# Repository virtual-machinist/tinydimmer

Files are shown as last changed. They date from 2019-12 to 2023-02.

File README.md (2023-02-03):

# Tinydimmer

LED dimmer with 1-10V control using ATtiny85 microcontroller.

## Motivation

An existing 1-10V controlled LED dimmer in my bathroom doesn't work well with dimmable Osram Superstar 2700K 7.8W MR16 lamps. Its dimming range start is below the minimum power at which the LED lamps start reliably.  
As a result the lamps start with a sudden flash after 1/3 turn of the dimmer controller pot. The 1-10V controlled dimmer I have doesn't have any means to adjust the dimming range, so I had to build my own.

## Parts Used

Here are some notes about parts used for this project. As usual I tend to reuse parts left from previous projects and even something scavenged from broken electronics, so not all parts are listed here.  
The case was printed using black Prusament PETG leftovers from the MK3S printer upgrade (<100g consumed in total).  
The PCB was ordered from JLCPCB. They once again did a fantastic job with Gerbers to delivered PCB in under a week.

`RV1` - originally planned to use a plain MOV (7N431K), but after assembling decided to switch for a Bourns 14D271K GMOV (basically a MOV and a gas discharge tube in one package) for improved safety.

`TR1` - a Hahn EL 305 2051 9V 3W PCB transformer. Just had one laying around. Open circuit gives ~17V AC, drops to 9V AC under rated load.

`D1`..`D4` - 1N5819 Schottky diodes. According to spec can withstand up to 28V RMS reverse voltage with <0.6V drop. Used purely for low voltage drop to give `U1` LDO some margin.

`U1` - Rohm BAJ0CC0T 10V LDO regulator. Probably some other LDO regulator can do, but bear in mind that it must work with `9 x 1.41 - 2 x 0.6 - 10 = 1.49V` dropout if using a 9V AC transformer. Consider choosing another transformer and LM7810 to keep things simpler.

`U2` - Digispark USB clone with ATtiny85 onboard. Brains of the operation.

`J1`, `J2` - CamdenBoss CTB7000 series cut-to-length terminal blocks. Bought actually as CTB7000/36 and, well, cut to length.

`C1` - 820uF 25V low ESR Panasonic capacitor. Could have gotten away with a much smaller value (`U1` spec mandates at least 0.33uF), but just didn't want to put some off-brand ones with smaller value.

`C3` - 47uF 16V tantalum capacitor. According to `U1` spec should be fairly large (at least 22uF) to prevent output oscillation.

`C4`, `C5` - 0.1uF 25V ceramic capacitors. Probably not needed on an actual PCB, but somewhat improved stability while prototyping.

`Q1` - IRL540N, but can be any logic-level n-channel MOSFET having the same pinout.

`R1` - 560R 1/4W resistor to limit current for the 1-10V Busch-Jaeger electronic potentiometer. Spec says it can sink up to 50mA. When prototyping with 12V Vcc I used 1K.

`RV2` - a 25k pot looking like from [ACP](https://www.acptechnologies.com/). I advise to adjust it a notch _below_ dead center so that voltage on its wiper is 4.98-4.99V to be on the safe side. We can remap anything in software after all.

`HS1` and `HS2` were taken from an old ATX PSU. The one for `Q1` isn't actually needed as it barely gets warm with 490Hz PWM. The one for `U1` is recommended though.

## Operation Mode

When referring to microcontroller pins I use the pin layout from the Digispark USB clone I have (`P0`..`P5`).

After power on and boot:

1. `P0` is checked for `HIGH`.

2. If `HIGH`, the control voltage is read as an analog value is from `P2` and divided by 4.

3. If control voltage value is less than low threshold, the minimum PWM value is written to `P1` (in my case 16, i.e. 6% duty cycle).

4. If control voltage value is less than high threshold (in my case 240), the maximum PWM value (255) is written to `P1`. Done because control voltage is not actually 10V, but in 9.7..9.8V range.

5. If `P0` is `LOW`, 0 is written to `P1` turning LEDs completely off.

6. Sleep for 100ms.

## ~~Known Issues~~ Room for Improvement

* Currently the dimmer is powered on constantly since I haven't yet figured out how to program ATTiny85 without a bootloader (or with a minimal one). Default boot times are over 2 seconds. This consumes ~2W at all times, so can add up to ~20kWH a year. Will definitely be revisiting this. [#1](https://github.com/virtual-machinist/tinydimmer/issues/1)

* The case warped a bit after cooling and could use a couple of more screws in the middle of the lid. And/or latches. My FreeCAD-fu is weak ATM. [#2](https://github.com/virtual-machinist/tinydimmer/issues/2)

## Photos

Working prototype:
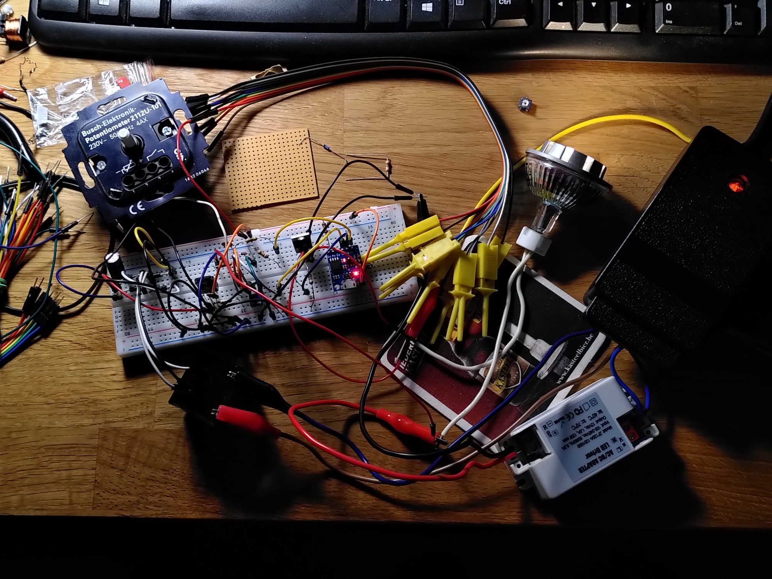
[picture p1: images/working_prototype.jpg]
Working prototype


Starting PCB assembly:
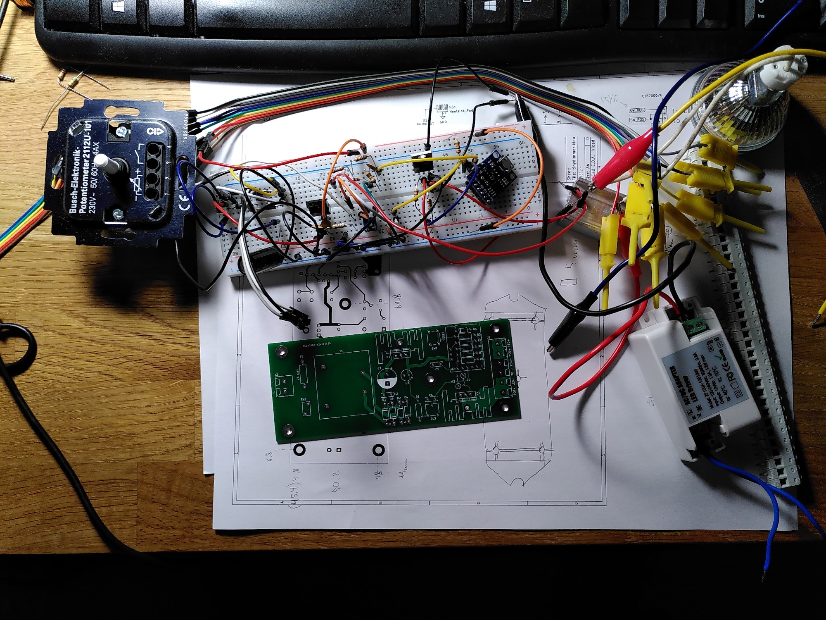
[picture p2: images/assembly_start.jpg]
Starting PCB assembly


Assembled PCB front:
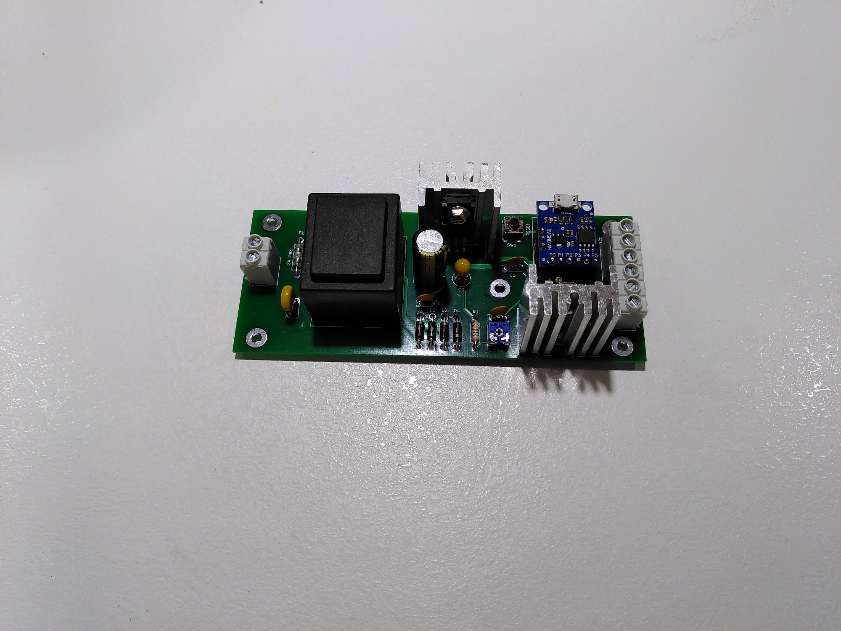
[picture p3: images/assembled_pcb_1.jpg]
Assembled PCB front


Assembled PCB back:
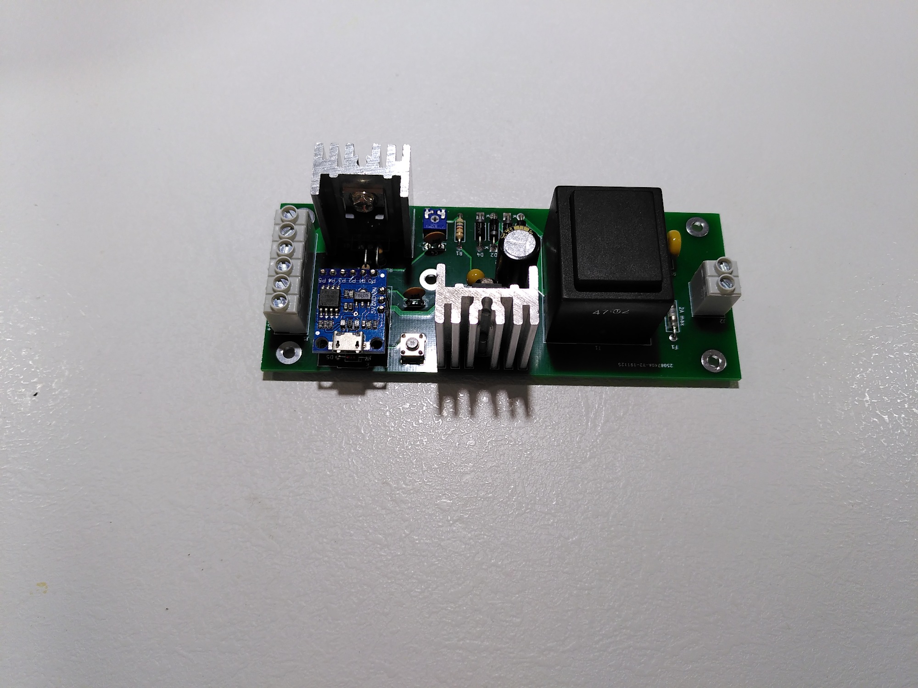
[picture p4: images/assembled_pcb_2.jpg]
Assembled PCB back


Assembled case:
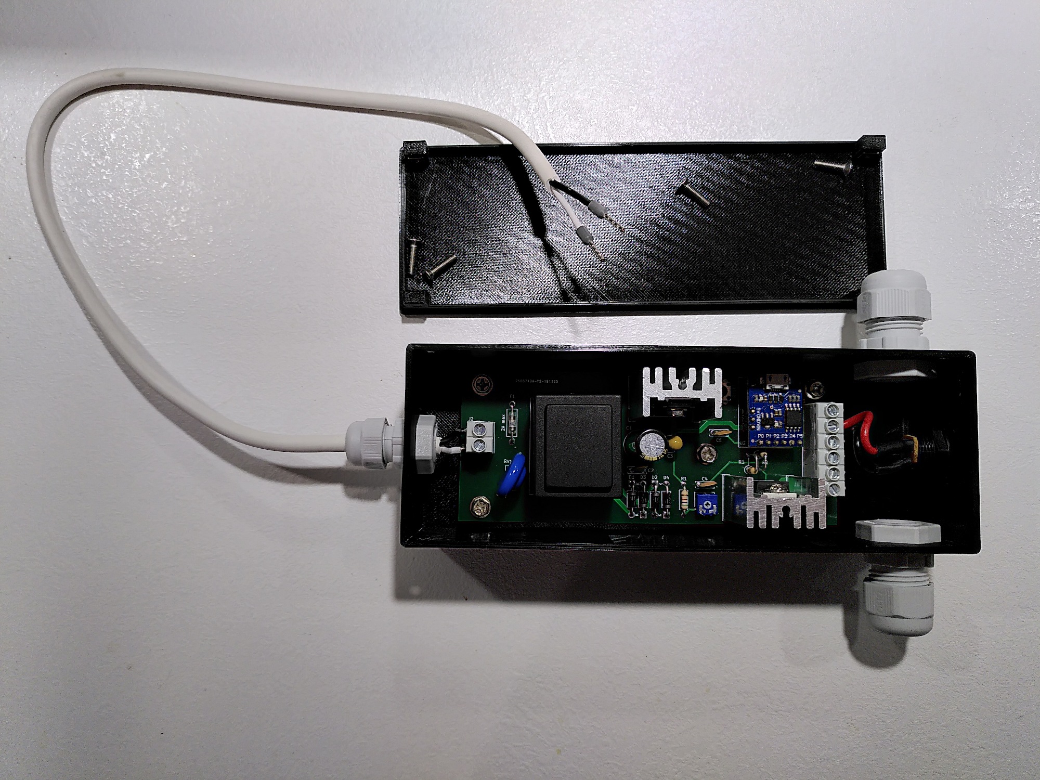
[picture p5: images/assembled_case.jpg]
Assembled case


## Contributing

If you have any questions or remarks for this design, feel free to open an issue.

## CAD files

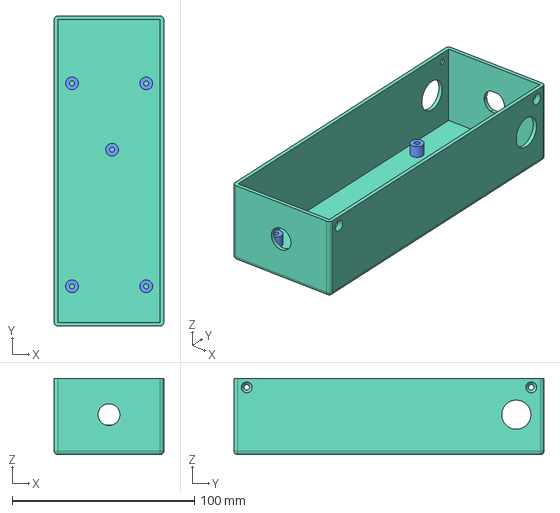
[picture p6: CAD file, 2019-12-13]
housing/Case Lower Half.FCStd
60.2 x 170.2 x 42.0 mm
Mount Shafts

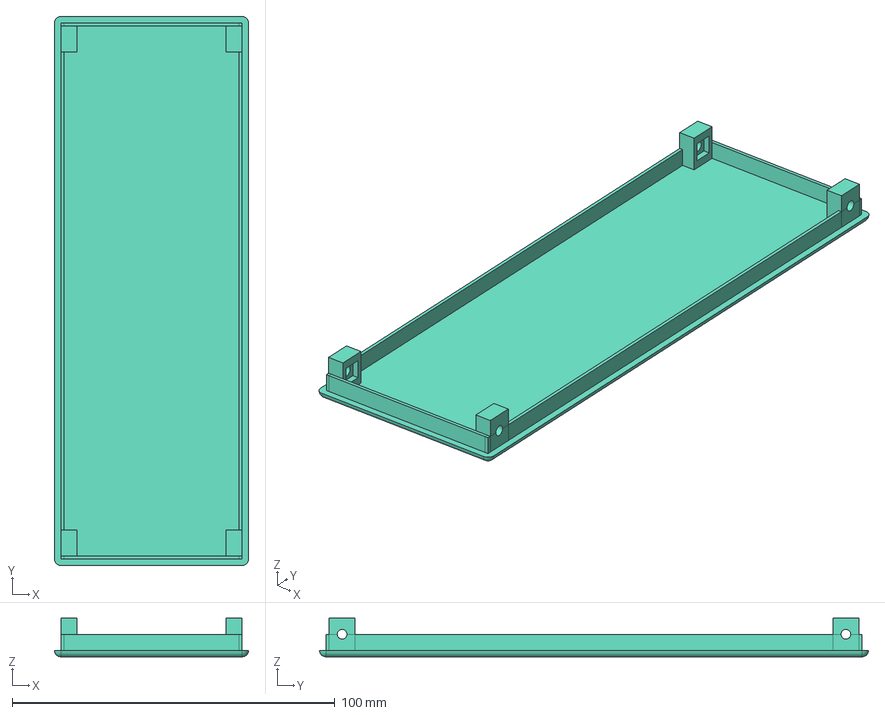
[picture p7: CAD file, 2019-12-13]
housing/Case Upper Half.FCStd
60.2 x 170.2 x 12.0 mm
Cap
Sealed Wall + Mounts

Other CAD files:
housing/Case Lower Half.stl
housing/Case Upper Half.stl

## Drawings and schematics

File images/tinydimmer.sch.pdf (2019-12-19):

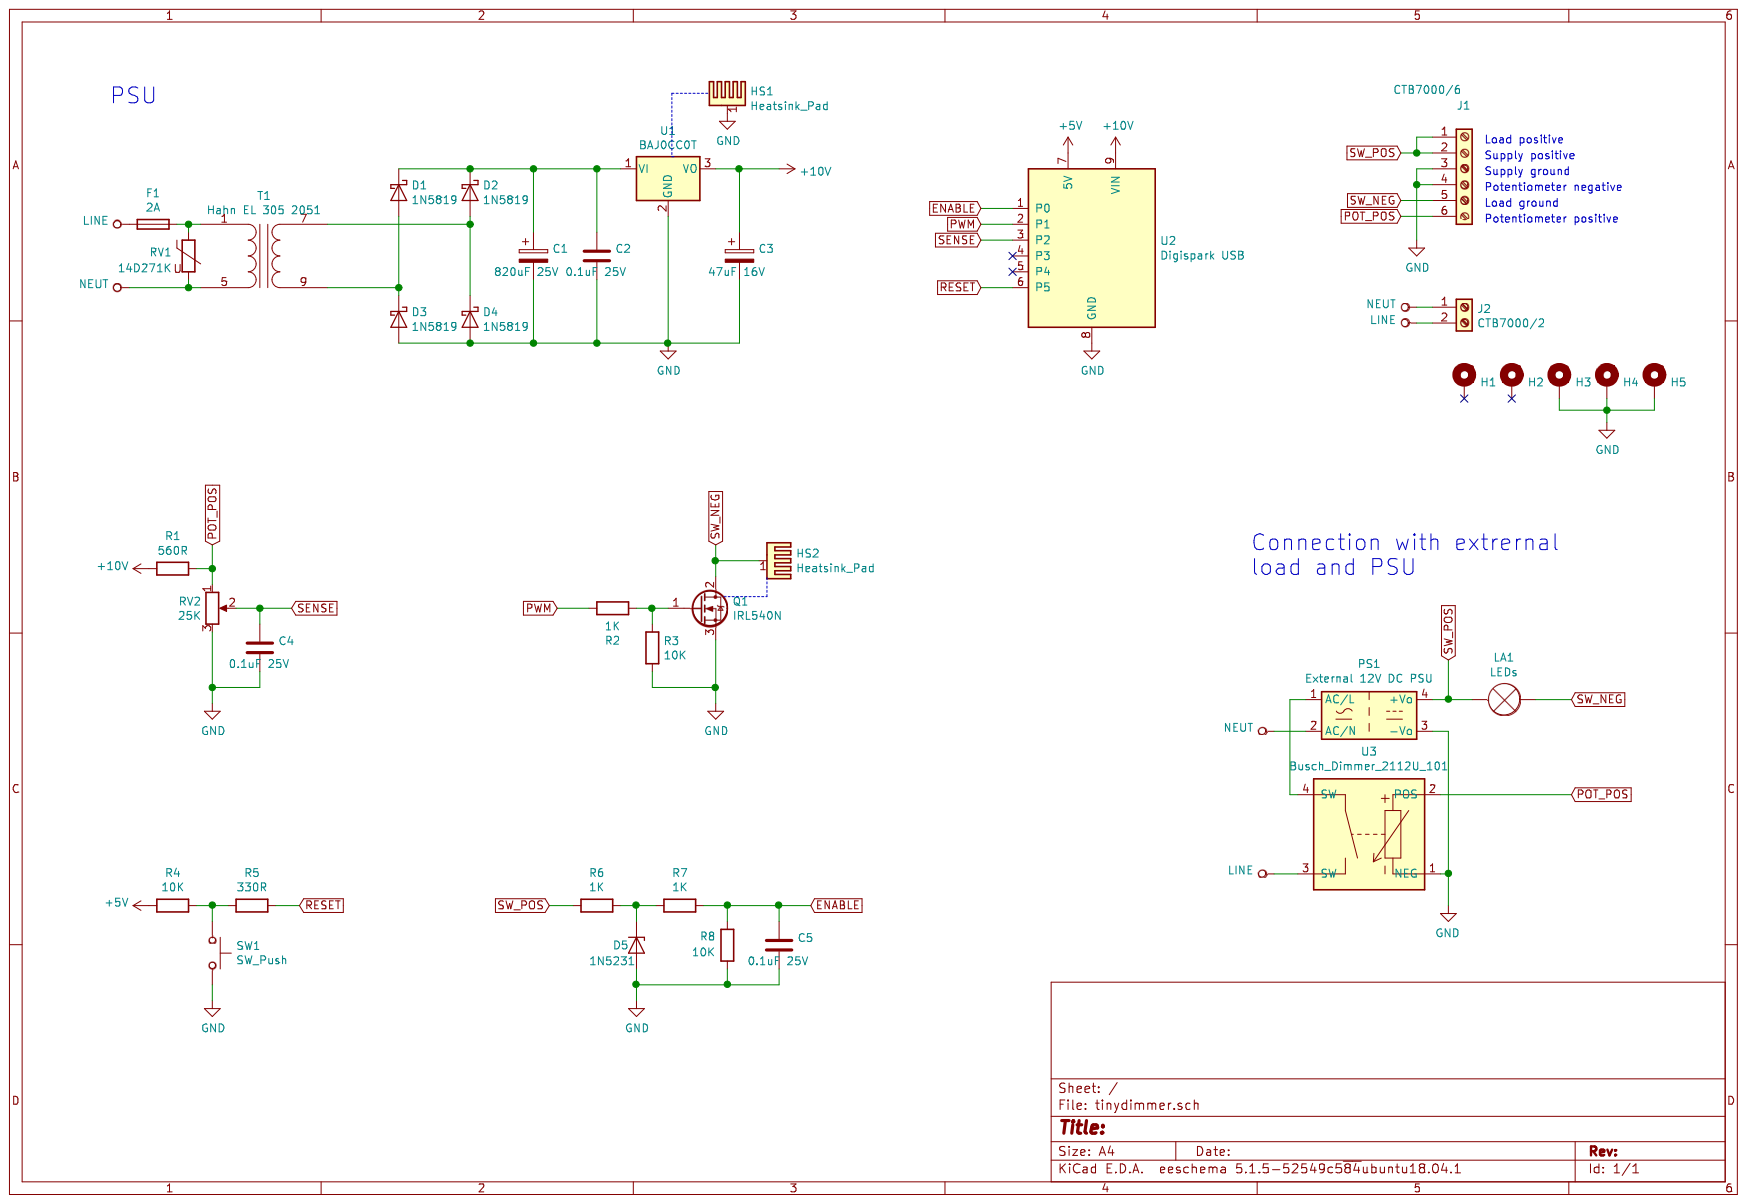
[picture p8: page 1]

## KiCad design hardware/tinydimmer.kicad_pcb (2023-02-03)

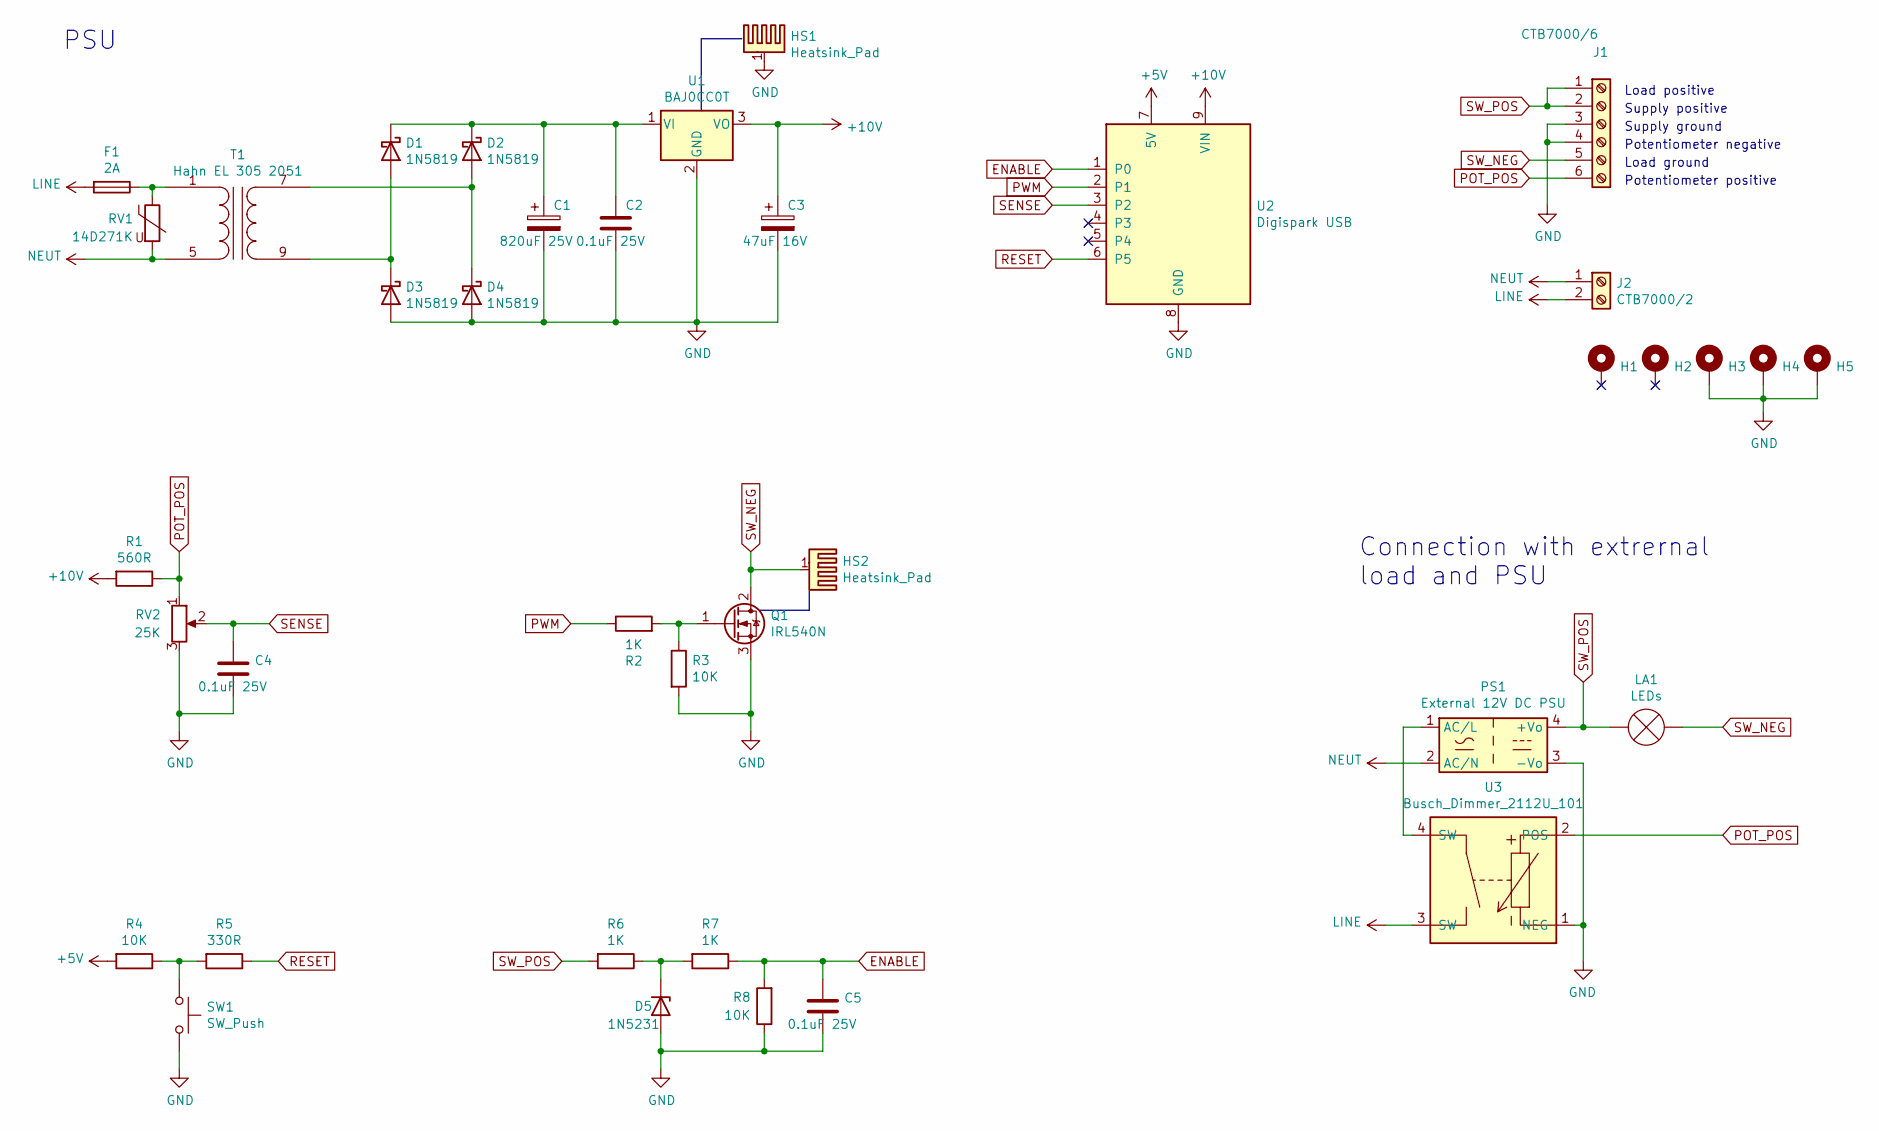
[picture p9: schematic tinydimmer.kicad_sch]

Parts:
C1: 820uF 25V; CP_Radial_D10.0mm_P5.00mm
C2, C4, C5: 0.1uF 25V; C_Disc_D6.0mm_W2.0mm_P3.81mm
C3: 47uF 16V; CP_Radial_Tantal_D5.5mm_P2.50mm
D1, D2, D3, D4: 1N5819; D_DO-41_SOD81_P10.16mm_Horizontal
D5: 1N5231; D_DO-35_SOD27_P7.62mm_Horizontal
F1: 2A; R_Axial_DIN0309_L9.0mm_D3.2mm_P12.70mm_Horizontal_Large_Pads
H1, H2, H3, H4, H5: MountingHole_Pad; MountingHole_3.2mm_M3_Pad
HS1, HS2: Heatsink_Pad; Heatsink_TO220_W23.5mm_L15.0mm_H30.0mm
J1: CTB7000/6; CamdenBoss_CTB7000_6_L30.0mm_P5.0mm
J2: CTB7000/2; CamdenBoss_CTB7000_2_L10.0mm_P5.0mm
LA1: LEDs
PS1: External 12V DC PSU
Q1: IRL540N; TO-220-3_Vertical
R1: 560R; R_Axial_DIN0207_L6.3mm_D2.5mm_P10.16mm_Horizontal
R2: 1K; R_Axial_DIN0207_L6.3mm_D2.5mm_P5.08mm_Vertical
R3: 10K; R_Axial_DIN0207_L6.3mm_D2.5mm_P5.08mm_Vertical
R4, R8: 10K; R_Axial_DIN0207_L6.3mm_D2.5mm_P10.16mm_Horizontal
R5: 330R; R_Axial_DIN0207_L6.3mm_D2.5mm_P10.16mm_Horizontal
R6, R7: 1K; R_Axial_DIN0207_L6.3mm_D2.5mm_P10.16mm_Horizontal
RV1: 14D271K; RV_Disc_D15.5mm_W3.9mm_P7.5mm
RV2: 25K; Potentiometer_ACP_CA6-V2,5_Vertical
SW1: SW_Push; SW_PUSH_6mm_H4.3mm
T1: Hahn EL 305 2051; Hahn_EL_305_2051
U1: BAJ0CC0T; TO-220-3_Vertical
U2: Digispark USB; Digispark_USB
U3: Busch_Dimmer_2112U_101

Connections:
+5V: R4.2, U2.7 (5V)
+10V: C3.1, R1.2, U1.3 (VO), U2.9 (VIN)
ENABLE: C5.1, R7.1, R8.2, U2.1 (P0)
GND: C1.2, C2.2, C3.2, C4.2, C5.2, D3.2 (A), D4.2 (A), D5.2 (A), H3.1, H4.1, H5.1, HS1.1, J1.3, J1.4, PS1.3 (-Vo), Q1.3 (S), R3.2, R8.1, RV2.3, SW1.2, U1.2 (GND), U2.8 (GND), U3.1 (NEG)
LINE: F1.2, J2.2, U3.3 (SW)
NEUT: J2.1, PS1.2 (AC/N), RV1.2, T1.5 (AB)
unnamed: C1.1, C2.1, D1.1 (K), D2.1 (K), U1.1 (VI)
unnamed: D1.2 (A), D3.1 (K), T1.9 (SA)
unnamed: D2.2 (A), D4.1 (K), T1.7 (SB)
unnamed: D5.1 (K), R6.1, R7.2
unnamed: F1.1, RV1.1, T1.1 (AA)
unnamed: PS1.1 (AC/L), U3.4 (SW)
unnamed: Q1.1 (G), R2.2, R3.1
unnamed: R4.1, R5.2, SW1.1
POT_POS: J1.6, R1.1, RV2.1, U3.2 (POS)
PWM: R2.1, U2.2 (P1)
RESET: R5.1, U2.6 (P5)
SENSE: C4.1, RV2.2, U2.3 (P2)
SW_NEG: HS2.1, J1.5, LA1.2 (+), Q1.2 (D)
SW_POS: J1.1, J1.2, LA1.1 (-), PS1.4 (+Vo), R6.2

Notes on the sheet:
Potentiometer negative
PSU
Supply ground
Supply positive
Potentiometer positive
Load positive
Load ground
Connection with extrernal load and PSU

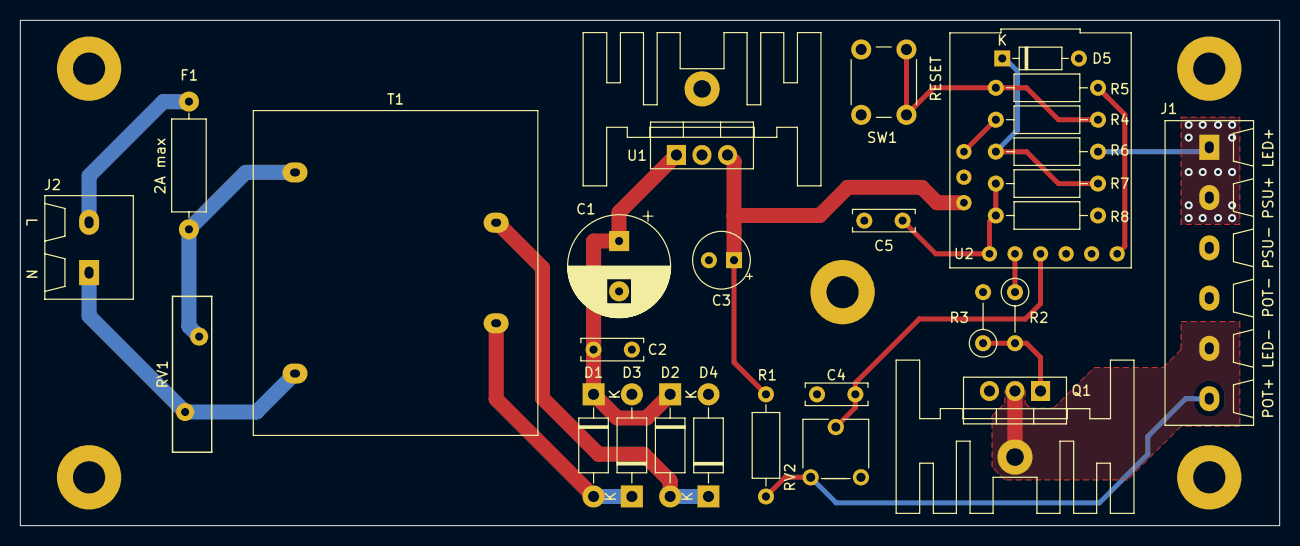
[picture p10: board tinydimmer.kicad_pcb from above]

Board: 2 copper layers, 125.2 x 50.2 mm, 35 parts (0 on the bottom side), 19 nets.

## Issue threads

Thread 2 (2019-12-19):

Account for case warping

virtual-machinist, 2019-12-19:
Current case design does not account for warping when printed with PETG.
After release from print substrate the bottom part of the case (box) becomes thicker thus disrupting the seal with the upper part (lid).
A couple of bolt mounts (similar to those done in corners) in the middle of the lid should help.

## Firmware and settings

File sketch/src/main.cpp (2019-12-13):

#include <Arduino.h>

const int minPwm = 16;
const int maxPwm = 255;
const int endClamp = 240;

extern int mapToPwm(int rawAnalogValue);

void setup()
{
	pinMode(0, INPUT);
	pinMode(1, OUTPUT);
}

void loop()
{
	int enabled = digitalRead(0);
	if (enabled == HIGH) {
		int potentiometerValue = analogRead(1);
		analogWrite(1, mapToPwm(potentiometerValue));
	} else {
		analogWrite(1, 0);
	}
	// poll 10 times a second
	delay(100);
}

int mapToPwm(int rawAnalogValue)
{
	// 10-bit DAC returns a value in 0..1023 range, but we need 8-bits for PWM
	int pwmValue = int(rawAnalogValue * 0.25);
	// but LEDs have erratic starting if PWM duty cycle is too low
	if (pwmValue < minPwm)
	{
		return minPwm;
	}
	// disable PWM if the value is very close to maximum
	else if (pwmValue > endClamp)
	{
		return maxPwm;
	}
	else
	{
		return pwmValue;
	}
}

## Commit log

2019-11-23 Initial commit
    Working Arduino prototype, custom symbols and footprints
    WIP: circuit diagram and PCB
    [tinydimmer.kicad_pcb, tinydimmer.sch]
2019-11-23 Adjust pads, rewire connectors, change footprints
    [tinydimmer.kicad_pcb, tinydimmer.sch]
2019-11-24 First PCB draft
    [tinydimmer.kicad_pcb, tinydimmer.sch]
2019-11-25 Make labels more visible
    Gerbers for first production batch
    [tinydimmer-B_Cu.gbr, tinydimmer-B_Mask.gbr, tinydimmer-B_Paste.gbr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]
2019-12-13 Replace plain MOV with a protected GMOV
    [tinydimmer.kicad_pcb, tinydimmer.sch]
2019-12-13 Lower full power threshold, increase poll rate
2019-12-13 Simple housing in FreeCAD
    [Case Lower Half.FCStd, Case Lower Half.stl, Case Upper Half.FCStd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]
2023-02-03 Migrate to KiCad 6
    [tinydimmer.kicad_pcb, tinydimmer.kicad_sch, tinydimmer.sch]
